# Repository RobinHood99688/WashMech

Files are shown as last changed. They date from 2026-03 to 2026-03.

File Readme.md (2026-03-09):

# Washmech

---

## 简介

Washmech是一款**可编程的可以发送和接收特定串口数据的模块**

V1.0版本的模块的主控是使用的STM32F030F4P6作为主控;有最多可以两个按钮控制串口数据发送,均支持长按短按双击;带有有源蜂鸣器作为响应

V2.0版本的模块的主控是使用的STM32C011F6P6作为主控,芯片成本更低

---

## 使用方法

每一个版本都是以一个文件夹的形式放出,例如'V1.0'版本文件夹.

各个版本的**使用方法**都会在其主文件夹贴出

每一个文件夹里面都至少包含PCB,Code,3D

其中PCB文件夹是板子的开源文件,可以使用嘉立创专业版打开

Code包含以Vscode+EIDE的开发方式的完整的一个可用工程的Project文件夹,以及专门的主要代码的main_code文件夹;其中main_code文件夹包含必要的库以及main.c,Project文件夹则是完整的工程的zip压缩文件

3D是可用的3D文件,包括SOLIDWORKS输出源文件以及可供拓竹打印机直接打印的文件

**每个版本的功能和方向都不同,详细请见具体版本**

---

## 未来方向

未来的版本可能会往远程控制以及屏幕输出的方向走,但是随之而来的就是更高的成本

---

本项目依旧在更新,当然你也可用联系我往你想要的方向做定制,all free

**个人研究学习,如有错误,欢迎指正**

**本产品为免费开源项目,任何人不能在未经允许下私自售卖**

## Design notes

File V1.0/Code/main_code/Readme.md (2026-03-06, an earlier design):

# WashMech V1.0

---

## 简介

V1.0是在特定环境下产生的特定版本.它的优势是体积小,成本低,约为3元以下,器件少;供电+5V;有两个按钮位置,可用根据实际情况焊接,建议只使用按钮1即可

## 注意事项

修改main.h中的SIGNAL_BUTTON_MODE宏即可一键切换单按钮或者双按钮模式

两种模式代码均测试过的,没有找到bug

---

**个人研究学习,如有错误,欢迎指正**

**本产品为免费开源项目,任何人不能在未经允许下私自售卖**

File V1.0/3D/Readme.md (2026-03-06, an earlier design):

# WashMech V1.0

---

现在还没有3D建模,后面会做一个小盒子,这样就可以环氧树脂灌胶封装,提高安全性;不然老被电

---

本项目依旧在更新,当然你也可用联系我往你想要的方向做定制,all free

**个人研究学习,如有错误,欢迎指正**

**本产品为免费开源项目,任何人不能在未经允许下私自售卖**

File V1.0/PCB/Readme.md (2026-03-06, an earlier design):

# WashMech V1.0

---

## 简介

V1.0是在特定环境下产生的特定版本.它的优势是体积小,成本低,约为3元以下,器件少;供电+5V;有两个按钮位置,可用根据实际情况焊接,建议只使用按钮1即可



正面



反面

(你所看到的这两根飞线是由于最开始的那一板接地不良好,但是工程里面的文件是接地良好的,不用飞线)

---

## BUG

先说说BUG,由于本人疏忽,忘记对照线序了,所以建议在实际上机之前先自己试一下怎么样才能正确输出

且PCB板上丝印版本是V1.0版本的,则TX和RX的丝印画反了,在后来的V1.1版本修改了,所以如果丝印上是V1.1的就没有反

---

本项目依旧在更新,当然你也可用联系我往你想要的方向做定制,all free

**个人研究学习,如有错误,欢迎指正**

**本产品为免费开源项目,任何人不能在未经允许下私自售卖**

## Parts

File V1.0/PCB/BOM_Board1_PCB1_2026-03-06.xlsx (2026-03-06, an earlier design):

No. | Quantity | Designator | Footprint | Value | Manufacturer Part | Manufacturer | Supplier Part | Supplier
1 | 1 | BUZZER1 | BUZ-TH_BD12.0-P7.60-D0.6-FD | 2.4kHz | TMB12A05 | 华能 | C96093 | LCSC
2 | 3 | C1,C2,C70 | C0603 | 100nF | CC0603KRX7R9BB104 | YAGEO(国巨) | C14663 | LCSC
3 | 1 | C3 | C0603 | 100nF | CGA0603X7R104K500JT | HRE(芯声) | C6119867 | LCSC
4 | 1 | C43 | C0603 | 1uF | CL10A105KB8NNNC | SAMSUNG(三星) | C15849 | LCSC
5 | 1 | C69 | C0603 | 10uF | CGA0603X5R106K100JT | HRE(芯声) | C6119842 | LCSC
6 | 1 | CN1 | CONN-TH_XH-4AW |  | XH-4AW | HCTL(华灿天禄) | C2908613 | LCSC
7 | 1 | D1 | SOD-123FL_L2.7-W1.8-LS3.8-RD |  | 1N4007W | R+O(宏嘉诚) | C18199088 | LCSC
8 | 1 | H1 | HDR-TH_4P-P2.54-V-F_MF254V-11-04-0743 |  | MF254V-11-04-0743 | XFCN(兴飞) | C2889986 | LCSC
9 | 1 | LED3 | LED0603-RD |  | NCD0603Y2 | 国星光电 | C89811 | LCSC
10 | 1 | Q1 | SOT-23-3_L2.9-W1.3-P1.90-LS2.3-BR |  | S8050 | R+O(宏嘉诚) | C20069125 | LCSC
11 | 6 | R1,R4,R5,R6,R24,R60 | R0603 | 10kΩ | 0603WAF1002T5E | UNI-ROYAL(厚声) | C25804 | LCSC
12 | 1 | R2 | R0603 | 0Ω | RC0603FR-070RL | YAGEO(国巨) | C100044 | LCSC
13 | 1 | R3 | R0603 | 1kΩ | FRC0603F1001TS | FOJAN(富捷) | C2907002 | LCSC
14 | 2 | SW3,SW4 | SW-SMD_L6.0-W6.0-P6.00-LS6.8 |  | OS4D501110 | SAMZO(三佐) | C42402920 | LCSC
15 | 1 | U1 | TSSOP-20_L6.5-W4.4-P0.65-LS6.4-BL |  | STM32F030F4P6 | ST(意法半导体) | C32908 | LCSC
16 | 1 | U53 | SOT-89_L4.5-W2.5-P1.50-LS4.2-BR |  | AMS1117-3.3S | UMW(友台半导体) | C347256 | LCSC

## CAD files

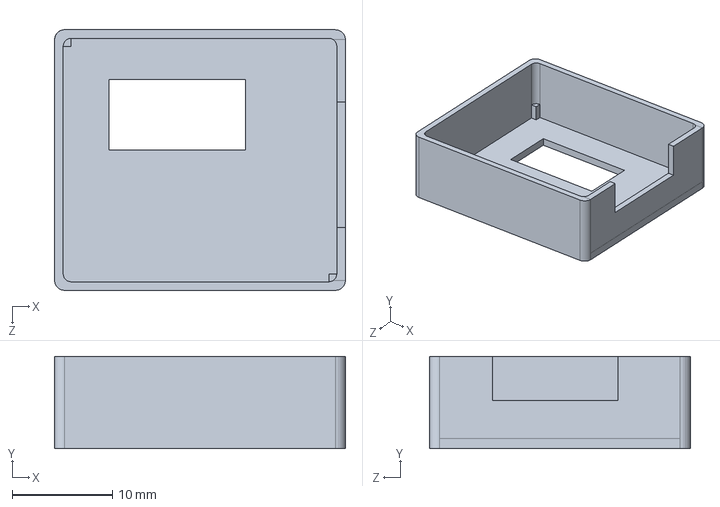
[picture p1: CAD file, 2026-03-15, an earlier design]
V1.0/3D/零件15.SLDPRT
29.0 x 9.20 x 26.0 mm

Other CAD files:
V1.0/3D/灌胶外壳.STL

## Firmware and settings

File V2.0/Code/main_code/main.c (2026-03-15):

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
/* Includes ------------------------------------------------------------------*/
#include "main.h"
#include "dma.h"
#include "tim.h"
#include "usart.h"
#include "gpio.h"

/* USER CODE BEGIN Includes */
#include "ButtonProcess.h"
/* USER CODE END Includes */

/* USER CODE BEGIN PM */

const char heart_pong[] = {0xaa, 0x06, 0x00, 0x9f, 0x02, 0x02, 0x3c, 0xc5};
const char heart_ping[] = {0xaa, 0x08, 0x00, 0x00, 0x00, 0x00, 0x00, 0x04, 0x7f, 0x30};

const char spin_dry[] = {0xaa, 0x06, 0x01, 0x98, 0x04, 0x00, 0x75, 0x03};
const char fb_spin_dry[] = {0xaa, 0x06, 0x00, 0x9f, 0x04, 0x00, 0xfb, 0xcc};
const char speed_wash[] = {0xaa, 0x06, 0x01, 0x98, 0x03, 0x01, 0xd0, 0xac};
const char fb_speed_wash[] = {0xaa, 0x06, 0x00, 0x9f, 0x03, 0x01, 0x5e, 0x63};
const char standard_wash[] = {0xaa, 0x06, 0x01, 0x98, 0x02, 0x02, 0xb2, 0x0a};
const char fb_standard_wash[] = {0xaa, 0x06, 0x00, 0x9f, 0x02, 0x02, 0x3c, 0xc5};

/* USER CODE END PM */


/* USER CODE BEGIN PV */

char receiveData[32] = {0};

BUTTON* button1;
bool button1_source = false;

uint8_t washMech_mode = 2;

/* USER CODE END PV */

void SystemClock_Config(void);
/* USER CODE BEGIN 0 */

void HAL_UARTEx_RxEventCallback(UART_HandleTypeDef *huart, uint16_t Size)
{ 
    if(huart == &huart2)
    {
        // heart_ping

        HAL_UARTEx_ReceiveToIdle_DMA(&huart2, (uint8_t *)receiveData, sizeof(receiveData));
    }
}

void button1_shortPress_callback(void* context)
{
    uint8_t* mode = (uint8_t *)context;

    *mode += 1;
    if(*mode >= 3)
        *mode = 0;

    switch(*mode)
    {
        case 2: HAL_TIM_PWM_Start(&htim16, TIM_CHANNEL_1); HAL_Delay(150); HAL_TIM_PWM_Stop(&htim16, TIM_CHANNEL_1); HAL_Delay(150);
        case 1: HAL_TIM_PWM_Start(&htim16, TIM_CHANNEL_1); HAL_Delay(150); HAL_TIM_PWM_Stop(&htim16, TIM_CHANNEL_1); HAL_Delay(150);
        case 0: HAL_TIM_PWM_Start(&htim16, TIM_CHANNEL_1); HAL_Delay(150); HAL_TIM_PWM_Stop(&htim16, TIM_CHANNEL_1); break;
        default : *mode = 0;
    }
}

void button1_longPress_callback(void* context)
{
    uint8_t* mode = (uint8_t *)context;

    switch(*mode)
    {
        case 0: HAL_UART_Transmit(&huart2, (uint8_t *)spin_dry, sizeof(spin_dry), 0x1000); break;
        case 1: HAL_UART_Transmit(&huart2, (uint8_t *)speed_wash, sizeof(speed_wash), 0x1000); break;
        case 2: HAL_UART_Transmit(&huart2, (uint8_t *)standard_wash, sizeof(standard_wash), 0x1000); break;
        default: break;
    }

    HAL_TIM_PWM_Start(&htim16, TIM_CHANNEL_1);
    HAL_Delay(600);
    HAL_TIM_PWM_Stop(&htim16, TIM_CHANNEL_1);

    HAL_Delay(3000);
    switch(*mode)
    {
        case 0: HAL_UART_Transmit(&huart2, (uint8_t *)fb_spin_dry, sizeof(fb_spin_dry), 0x1000); break;
        case 1: HAL_UART_Transmit(&huart2, (uint8_t *)fb_speed_wash, sizeof(fb_speed_wash), 0x1000); break;
        case 2: HAL_UART_Transmit(&huart2, (uint8_t *)fb_standard_wash, sizeof(fb_standard_wash), 0x1000); break;
        default: break;
    }

    HAL_TIM_PWM_Start(&htim16, TIM_CHANNEL_1);
    HAL_Delay(300);
    HAL_TIM_PWM_Stop(&htim16, TIM_CHANNEL_1);
}

/* USER CODE END 0 */

/**
  * @brief  The application entry point.
  * @retval int
  */
int main(void)
{

  /* MCU Configuration--------------------------------------------------------*/

  /* Reset of all peripherals, Initializes the Flash interface and the Systick. */
  HAL_Init();

  /* Configure the system clock */
  SystemClock_Config();

  /* Initialize all configured peripherals */
  MX_GPIO_Init();
  MX_DMA_Init();
  MX_USART2_UART_Init();
  MX_TIM16_Init();
  /* USER CODE BEGIN 2 */

  button1 = create_button(BUTTON_Pin, false, true, High_Active, 40, 30, 650, 350, 30);
  set_shortPress_event(button1, button1_shortPress_callback, &washMech_mode);
  set_longPress_event(button1, button1_longPress_callback, &washMech_mode);

  HAL_UARTEx_ReceiveToIdle_DMA(&huart2, (uint8_t *)receiveData, sizeof(receiveData));

  /* USER CODE END 2 */

  /* Infinite loop */
  /* USER CODE BEGIN WHILE */
  while (1)
  {
    updata_button(button1);

    /* USER CODE END WHILE */

    /* USER CODE BEGIN 3 */
  }
  /* USER CODE END 3 */
}

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

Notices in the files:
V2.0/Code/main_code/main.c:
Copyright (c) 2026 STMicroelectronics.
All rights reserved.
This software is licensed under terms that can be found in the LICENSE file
